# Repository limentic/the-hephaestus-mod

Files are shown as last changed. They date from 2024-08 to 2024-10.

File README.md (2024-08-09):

# The Hephaestus Mod

## ⚠️ DISCLAIMER ⚠️
Magic Keyboard is a trademark of Apple Inc.\
Apple Magic Keyboard is a trademark of Apple Inc.\
Touch ID is a trademark of Apple Inc.\
This project is not affiliated with Apple Inc. in any way.

The Hephaestus Mod is an independent project created by hardware enthusiasts. It is not endorsed, sponsored, ore supported by Apple Inc. Use this project at your own risk. Modifying your Magic Keyboard WILL void any warranty provided by Apple Inc.

## Introduction
The Hephaestus Mod is an open-source hardware modification for the Apple Magic Keyboard. This project aims create a mechanical keyboard using the Apple Magic Keyboard as a base.

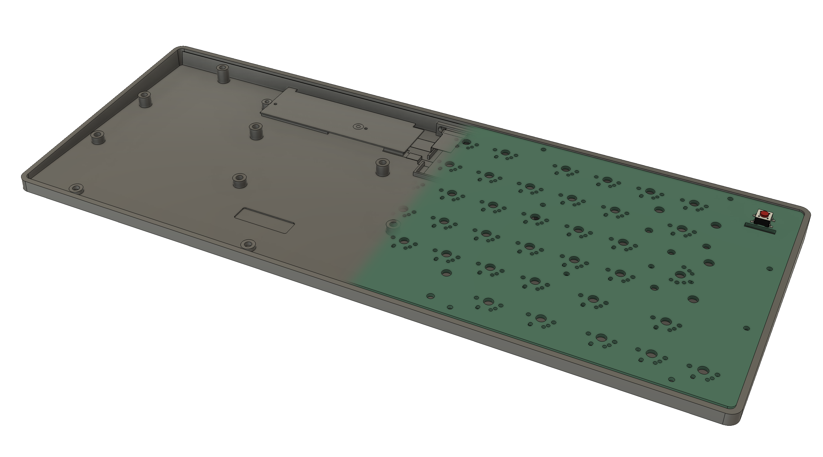
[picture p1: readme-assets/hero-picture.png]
Photomontage of a 3D render of the custom 3D printed case with the half right of the custom PCB on top of it.


## Getting Started
The Hephaestus Mod project is organized into the following directories:
- `ECAD-files/` - Contains the KiCad project files for the Hephaestus Mod.
    In this directory, you will find the following subdirectories:
    - `dev-board/` - Contains the KiCad project files for the development board. This board was used to test out if the reverse engineered keyboard matrix was correct.
    It can also be repurposed as a breakout board for the matrix connector. \
    **Be careful!** The revision 1.0 of the board contains errors for the 9, TAB and Option Right keys. I will make another revision of the dev board when I have time.
    - `prod-board/` - Contains the KiCad project files for the production board. This board is the version of the Hephaestus Mod that is intended to be used. \
    **Be careful!** For the moment this board is still not tested. It is still in manufacturing. I will update this README when I have tested it and confirmed that it works.
    - `touch-id-ribbon` - Contains the KiCad project files for the Touch ID ribbon cable. This cable is used to connect the Touch ID connector on the Apple motherboard to the production board.
- `MCAD-files/` - Contains the .STEP files of the Hephaestus Mod.
    - `hephaestus-case.step` - The case for the Hephaestus Mod.
    - `hephaestus-main-board.step` - The 3D model of the production board.
    - `magic-keyboard-battery.step` - The 3D model of the Magic Keyboard battery.
    - `magic-keyboard-motherboard.step` - The 3D model of the Magic Keyboard motherboard.

## Presumed Keyboard Matrices
You can check the presumed keyboard matrices below :
- [AZERTY Keyboard Matrix](./matrices/AZERTY.md)

## Build Instructions
🚧 **This section will be updated with instructions on how to get started with the Hephaestus Mod when the project is considered done.** 🚧

## License
This project is licensed under the CERN-OHL-S. See the [LICENSE](LICENSE) file for details.

## Contributing
We welcome contributions! Please read our [contributing guidelines](CONTRIBUTING.md) for more information on how to get involved.

## Contact
For questions, issues, or suggestions, please open an issue on our [GitHub repository](https://github.com/limentic/the-hephaestus-mod).

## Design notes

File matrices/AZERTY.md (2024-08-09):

## Key pins :
| Keys | Pin A | Pin B |
|---|---|---|
| ESC | 7 | 27 |
| F1 | 3 | 26 |
| F2 | 7 | 26 |
| F3 | 8 | 26 |
| F4 | 17 | 26 |
| F5 | 21 | 26 |
| F6 | 29 | 26 |
| F7 | 25 | 26 |
| F8 | 28 | 26 |
| F9 | 30 | 26 |
| F10 | 24 | 27 |
| F11 | 3 | 27 |
| F12 | 3 | 19 |
| # | 8 | 19 |
| 1 | 3 | 1 |
| 2 | 7 | 1 |
| 3 | 8 | 1 |
| 4 | 17 | 1 |
| 5 | 21 | 1 |
| 6 | 29 | 1 |
| 7 | 25 | 1 |
| 8 | 28 | 1 |
| 9 | 30 | 1 |
| 0 | 23 | 27 |
| ° | 21 | 27 |
| _ | 29 | 19 |
| BACKSPACE | 3 | 22 |
| TAB | 7 | 22 |
| A | 3 | 15 |
| Z | 7 | 2 |
| E | 8 | 16 |
| R | 17 | 2 |
| T | 21 | 15 |
| Y | 29 | 15 |
| U | 25 | 15 |
| I | 28 | 15 |
| O | 30 | 15 |
| P | 11 | 27 |
| ¨ | 21 | 19 |
| * | 17 | 19 |
| ENTER | 9 | 27 |
| CAPS_LOCK | 11 | 22 |
| Q | 3 | 18 |
| S | 7 | 13 |
| D | 8 | 14 |
| F | 17 | 18 |
| G | 21 | 13 |
| H | 29 | 18 |
| J | 25 | 18 |
| K | 28 | 18 |
| L | 30 | 18 |
| M | 25 | 27 |
| % | 25 | 22 |
| £ | 30 | 27 |
| SHIFT_L | 9 | 15 |
| > | 7 | 19 |
| W | 3 | 20 |
| X | 7 | 20 |
| C | 8 | 20 |
| V | 17 | 14 |
| B | 21 | 14 |
| N | 29 | 20 |
| ? | 25 | 20 |
| . | 28 | 20 |
| / | 30 | 20 |
| + | 29 | 27 |
| SHIFT_R | 9 | 26 |
| FN | 21 | 22 |
| CTRL | 11 | 1 |
| OPTION_L | 24 | 18 |
| COMMAND_L | 23 | 20 |
| SPACE | 24 | 16 |
| COMMAND_R | 23 | 19 |
| OPTION_R | 24 | 22 |
| LEFT_ARROW | 25 | 19 |
| UP_ARROW | 28 | 27 |
| DOWN_ARROW | 28 | 22 |
| RIGHT_ARROW | 30 | 19 |

## Other pins :
| Label | Pins | Notes |
|---|---|---|
| CAPS_LOCK_LED_+ | 5-6 | ~3,23V |
| CAPS_LOCK_LED_- | 10 | Not connected to GND |
| NC (GND) | 4,12,33-40 | |
| PWR | 31-32 | |

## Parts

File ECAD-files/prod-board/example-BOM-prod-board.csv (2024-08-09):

Item | Designator | Qty | Manufacturer | Mfg Part | Description/Value | Package/Footprint | Type | Notes
1 | D1 | 1 | Lite-On | LTST-C170TGKT | LED 3.2V 20mA 525nm 0805 SMD | 0805 | SMD | Accepts alternatives. Any green led with the same characteristics is OK.
2 | J1 | 1 | Hirose | FH12-40S-0.5SH | Connector 1x40 P0.50mm | Non-standard | SMD
3 | J2 | 1 | Hirose | TF22-16S-0.175SHW(800) | Connector 2x8 P0.35mm | Non-standard | SMD
4 | J3 | 1 | Molex | 505066-1222 | Connector 2x6 P0.35mm | Non-standard | SMD
5 | K_SPACE0,K_SPACE1,K_SPACE2,K_SPACE3,K_SPACE4,K_SPACE5,K_SPACE6,K_SPACE7,K_SPACE8,K_SPACE9,K_SPACE10,K_SPACE11,K_SPACE12,K_SPACE14,K_SPACE15,K_SPACE16,K_SPACE17,K_SPACE18,K_SPACE19,K_SPACE20,K_SPACE21,K_SPACE22,K_SPACE23,K_SPACE24,K_SPACE25,K_SPACE26,K_SPACE27,K_SPACE28,K_SPACE29,K_SPACE30,K_SPACE31,K_SPACE32,K_SPACE33,K_SPACE34,K_SPACE35,K_SPACE36,K_SPACE37,K_SPACE38,K_SPACE39,K_SPACE40,K_SPACE41,K_SPACE42,K_SPACE43,K_SPACE44,K_SPACE45,K_SPACE46,K_SPACE47,K_SPACE48,K_SPACE49,K_SPACE50,K_SPACE51,K_SPACE52,K_SPACE53,K_SPACE54,K_SPACE55,K_SPACE56,K_SPACE57,K_SPACE58,K_SPACE59,K_SPACE60,K_SPACE61,K_SPACE62,K_SPACE63,K_SPACE64,K_SPACE65,K_SPACE66,K_SPACE67,K_SPACE68,K_SPACE69,K_SPACE70,K_SPACE71,K_SPACE72,K_SPACE73,K_SPACE74,K_SPACE75,K_SPACE76,K_SPACE77,K_SPACE78 | 78 | Cherry | MX1A-E1NW | Switch SPST Cherry MX Blue (PCB Mount) | Non-standard | thru-hole
6 | SW1 | 1 | Molex | 53261-0271 | Connector 1x2 P1.25mm | Non-standard | SMD
7 | SW2 | 1 | C&K | PTS645-SK-50-SMTR92-LFS | Switch SPST | Non-standard | SMD | Accepts alternatives. The stem should be around 1.5mm.

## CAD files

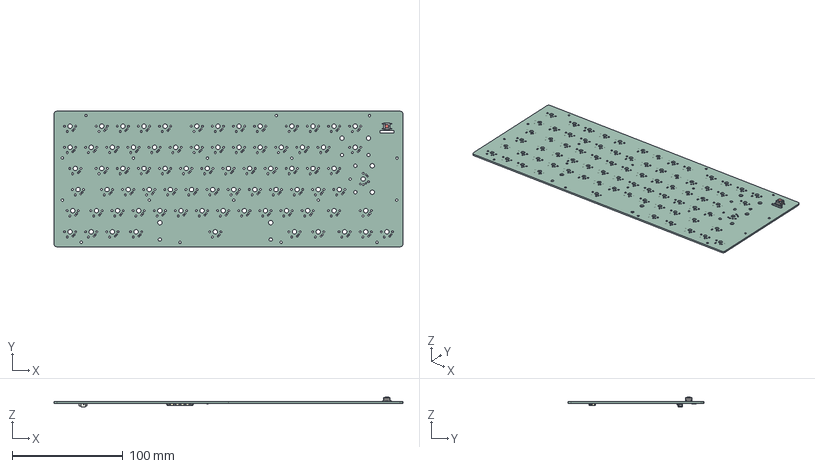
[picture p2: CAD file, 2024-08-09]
MCAD-files/hephaestus-main-board.step
314.8 x 122.3 x 9.40 mm
SW_SPST_PTS645_1
Hirose_FH12_xxS_0_5SH_Parametric_v0_1
Molex_53261_0271
_autosave-keyboard_PCB

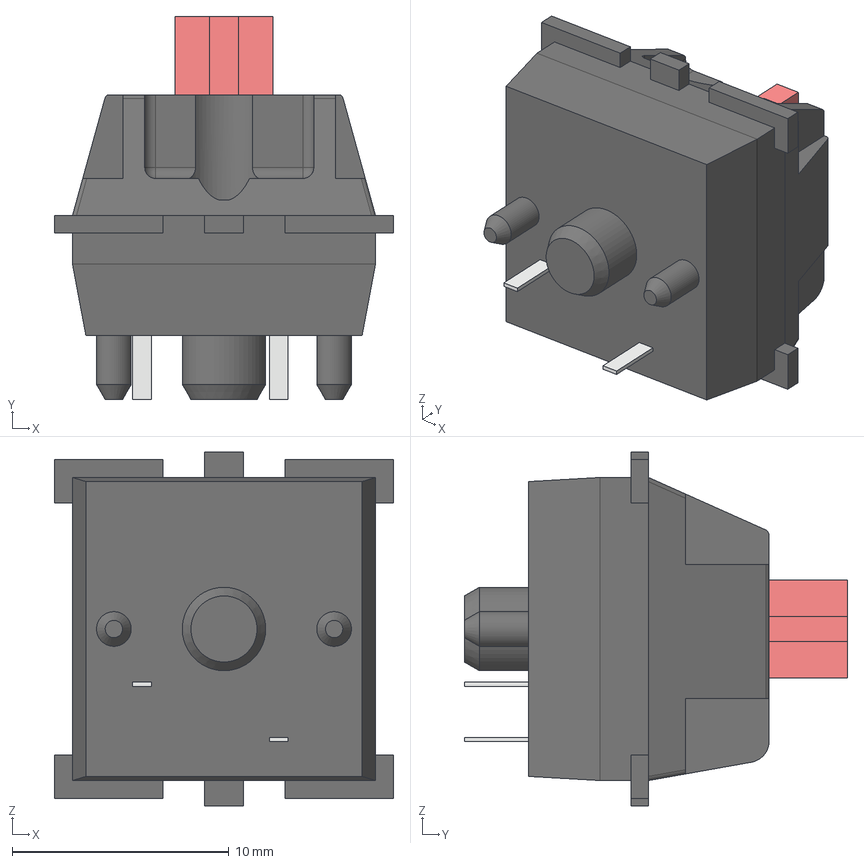
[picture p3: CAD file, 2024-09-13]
ECAD-files/prod-board/cherry-mx-switch/switch.step
15.6 x 17.7 x 16.3 mm

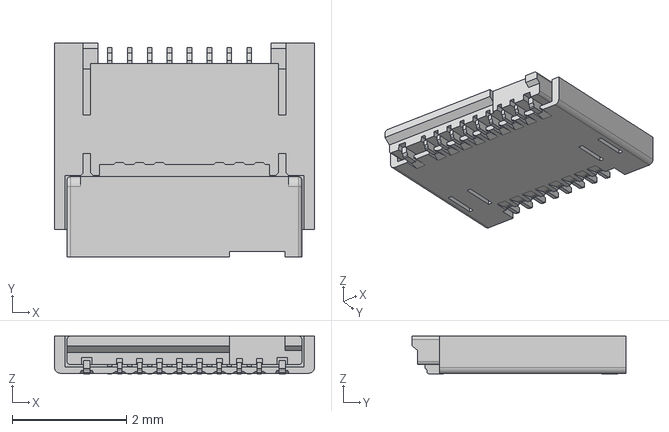
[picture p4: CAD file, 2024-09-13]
ECAD-files/prod-board/TF22-16S/TF22-16S-0.175SHW(800)_4800346000_3D_IGS.igs
4.55 x 3.75 x 0.66 mm

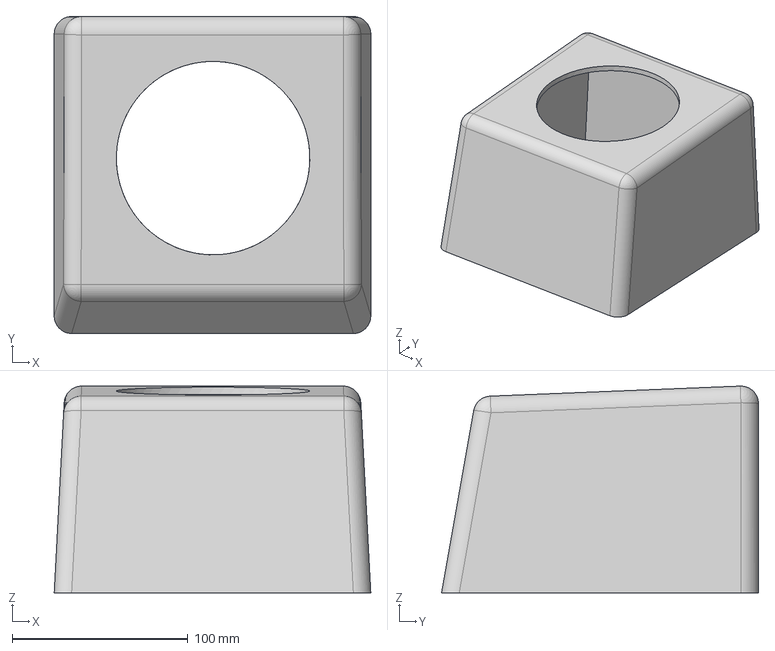
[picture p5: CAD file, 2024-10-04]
MCAD-files/keycap-cover.step
180.0 x 180.2 x 117.6 mm

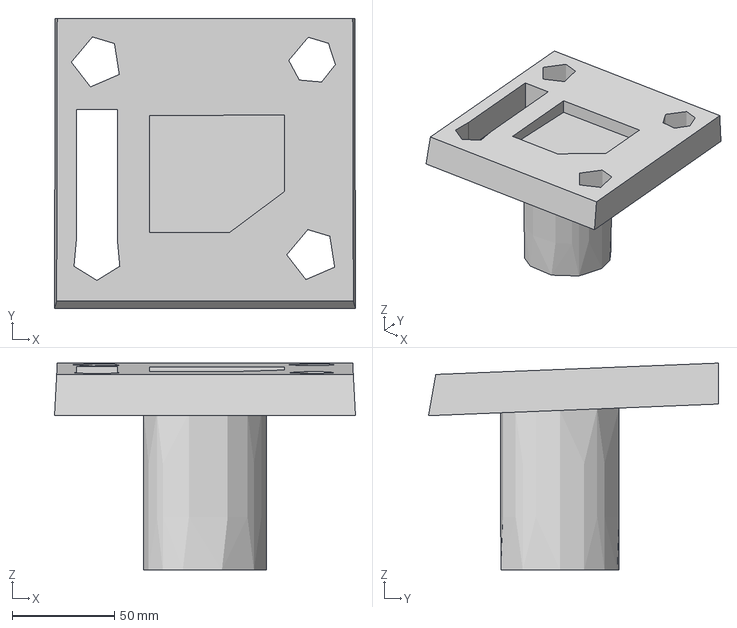
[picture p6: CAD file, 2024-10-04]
MCAD-files/keycap-stem.step
147.1 x 141.7 x 101.1 mm

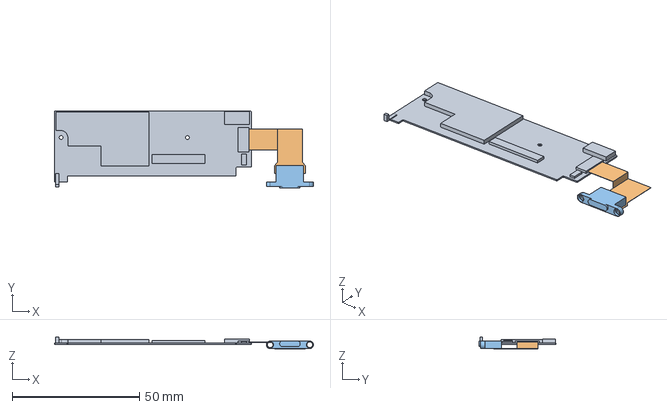
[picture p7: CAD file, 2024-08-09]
MCAD-files/magic-keyboard-motherboard.step
101.6 x 30.3 x 4.63 mm

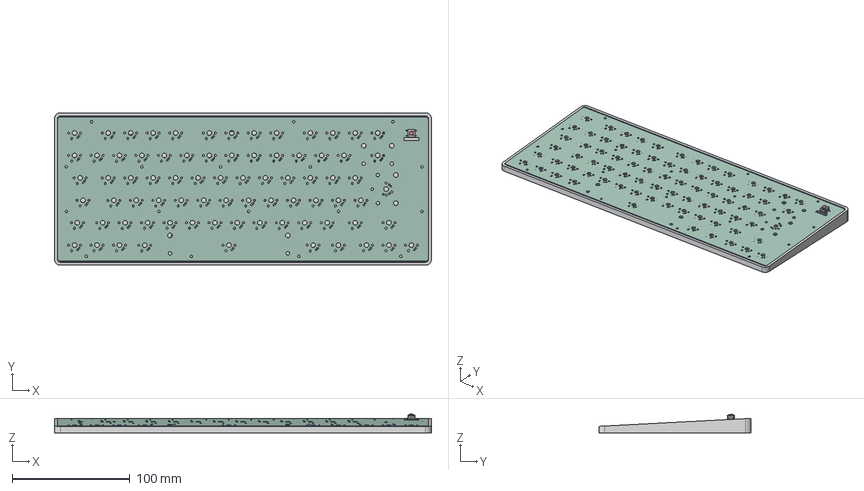
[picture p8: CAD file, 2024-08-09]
MCAD-files/hephaestus-case.step
319.8 x 129.3 x 15.8 mm
SW_SPST_PTS645_1
Hirose_FH12_xxS_0_5SH_Parametric_v0_1
Molex_53261_0271
_autosave-keyboard_PCB
magic-keyboard-motherboard
magic-keyboard-battery

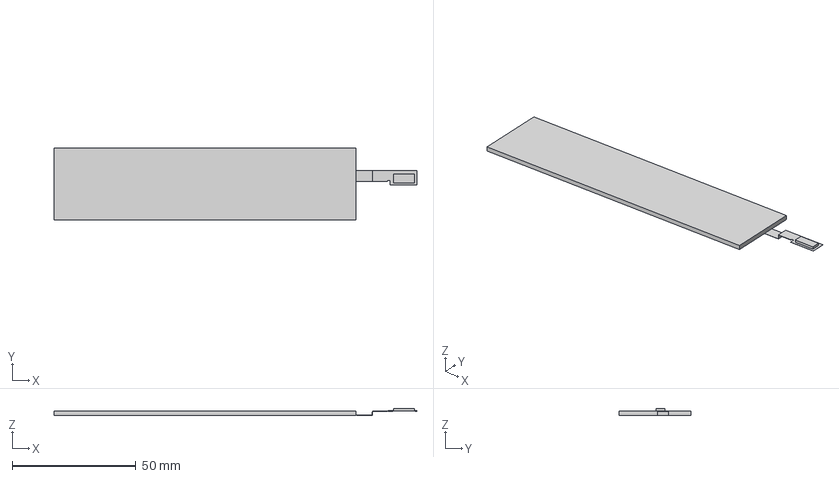
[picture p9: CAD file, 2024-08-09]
MCAD-files/magic-keyboard-battery.step
146.7 x 29.0 x 2.81 mm

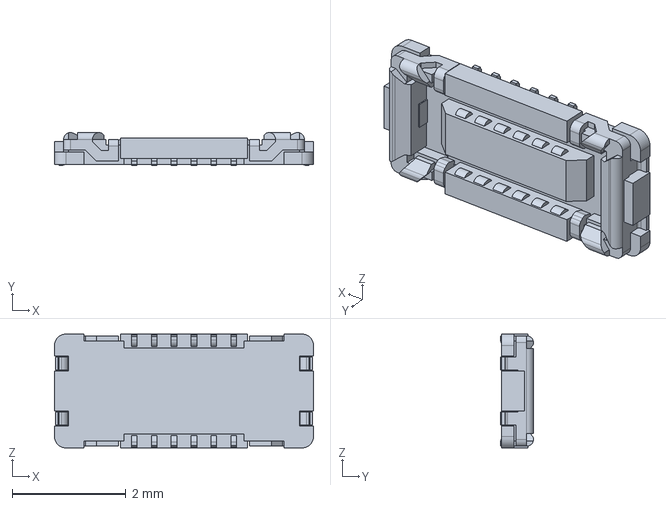
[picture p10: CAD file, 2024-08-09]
ECAD-files/prod-board/505066-1222/505066-1222.stp
4.55 x 0.58 x 2.00 mm

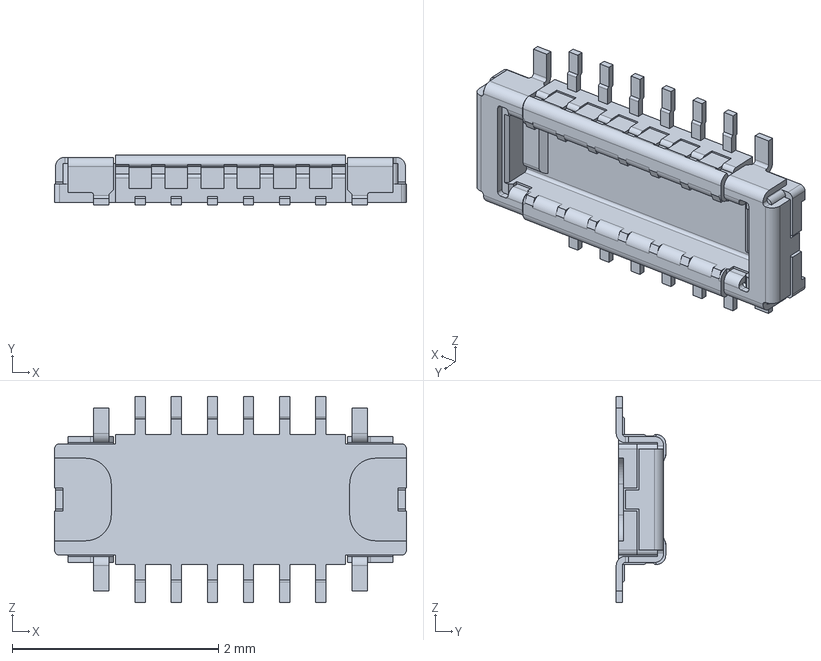
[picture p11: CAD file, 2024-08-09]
ECAD-files/touch-id-ribbon/505070-1222/505070-1222.step
3.41 x 0.48 x 2.00 mm

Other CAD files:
ECAD-files/touch-id-ribbon/505070-1222/505070-1222.stp

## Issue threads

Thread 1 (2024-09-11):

is the touchid housing keycap part of this project?

aescolastico, 2024-09-11:
hello,
first off, cool project. this is amazing work.

second, i saw your post on GH where you prototyped a keycap for the touch id sensor.
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

would you be willing to add that to the repo? or if it is already, can you please direct me to that file?

im planning on doing a much less integrated and involved mod, where i simply store the control board in an existing mech keeb's housing and replace my escape key cap with a touch id one, feeding the ribbon behind the mechs pcb.

limentic, 2024-09-13:
Hello, sorry for the delay.
I lost the original file and had to remake it for someone who emailed me a few weeks ago.
I can create a new branch with the keycap so you can test it and let me know if it's okay.

aescolastico, 2024-09-13:
> Hello, sorry for the delay. I lost the original file and had to remake it for someone who emailed me a few weeks ago. I can create a new branch with the keycap so you can test it and let me know if it's okay.

one question, what unit are the keycap and stem stl files in?

limentic, 2024-09-13:
milimeters :)

aescolastico, 2024-10-04:
> Hello, sorry for the delay. I lost the original file and had to remake it for someone who emailed me a few weeks ago. I can create a new branch with the keycap so you can test it and let me know if it's okay.

so i got a few pieces printed in different resin materials. it seems that the stem has too much play on the "female" side to stay on the switch. it wobbles when you try to press it. it guess its also possible the print was just off?

would you happen to still have the source files? i may try to take a stab at modifying them to closer match the profile of my LP key caps. the stem is shorter and so is the key cap face.

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

limentic, 2024-10-04:
I'm so sorry for the bad files I've provided to you . As I've said before, I don't have the original files, thoses were re-creations, I've made new files in .step from the previous version of the keycap.
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

Let me know if you tweak it and make it work !
Good luck!

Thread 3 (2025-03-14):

Swapping the lightning connector for USB-C

ataulm, 2025-03-14:
Great write up of the project on GH! 👏

I disassembled my Magic KB this week with the intention of baking just the touch ID into my desk.

I noticed on the first post of the thread that you mentioned that you want to swap the lightning port for a usb c port: did you have a plan for this yet?

I'd like to do the same but no idea if I can buy a port that has the same connection.

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

Also unclear to me whether I can shorten this PCB if I'm only interested in the touch ID - presumably that metal cover is housing the controller 🥲

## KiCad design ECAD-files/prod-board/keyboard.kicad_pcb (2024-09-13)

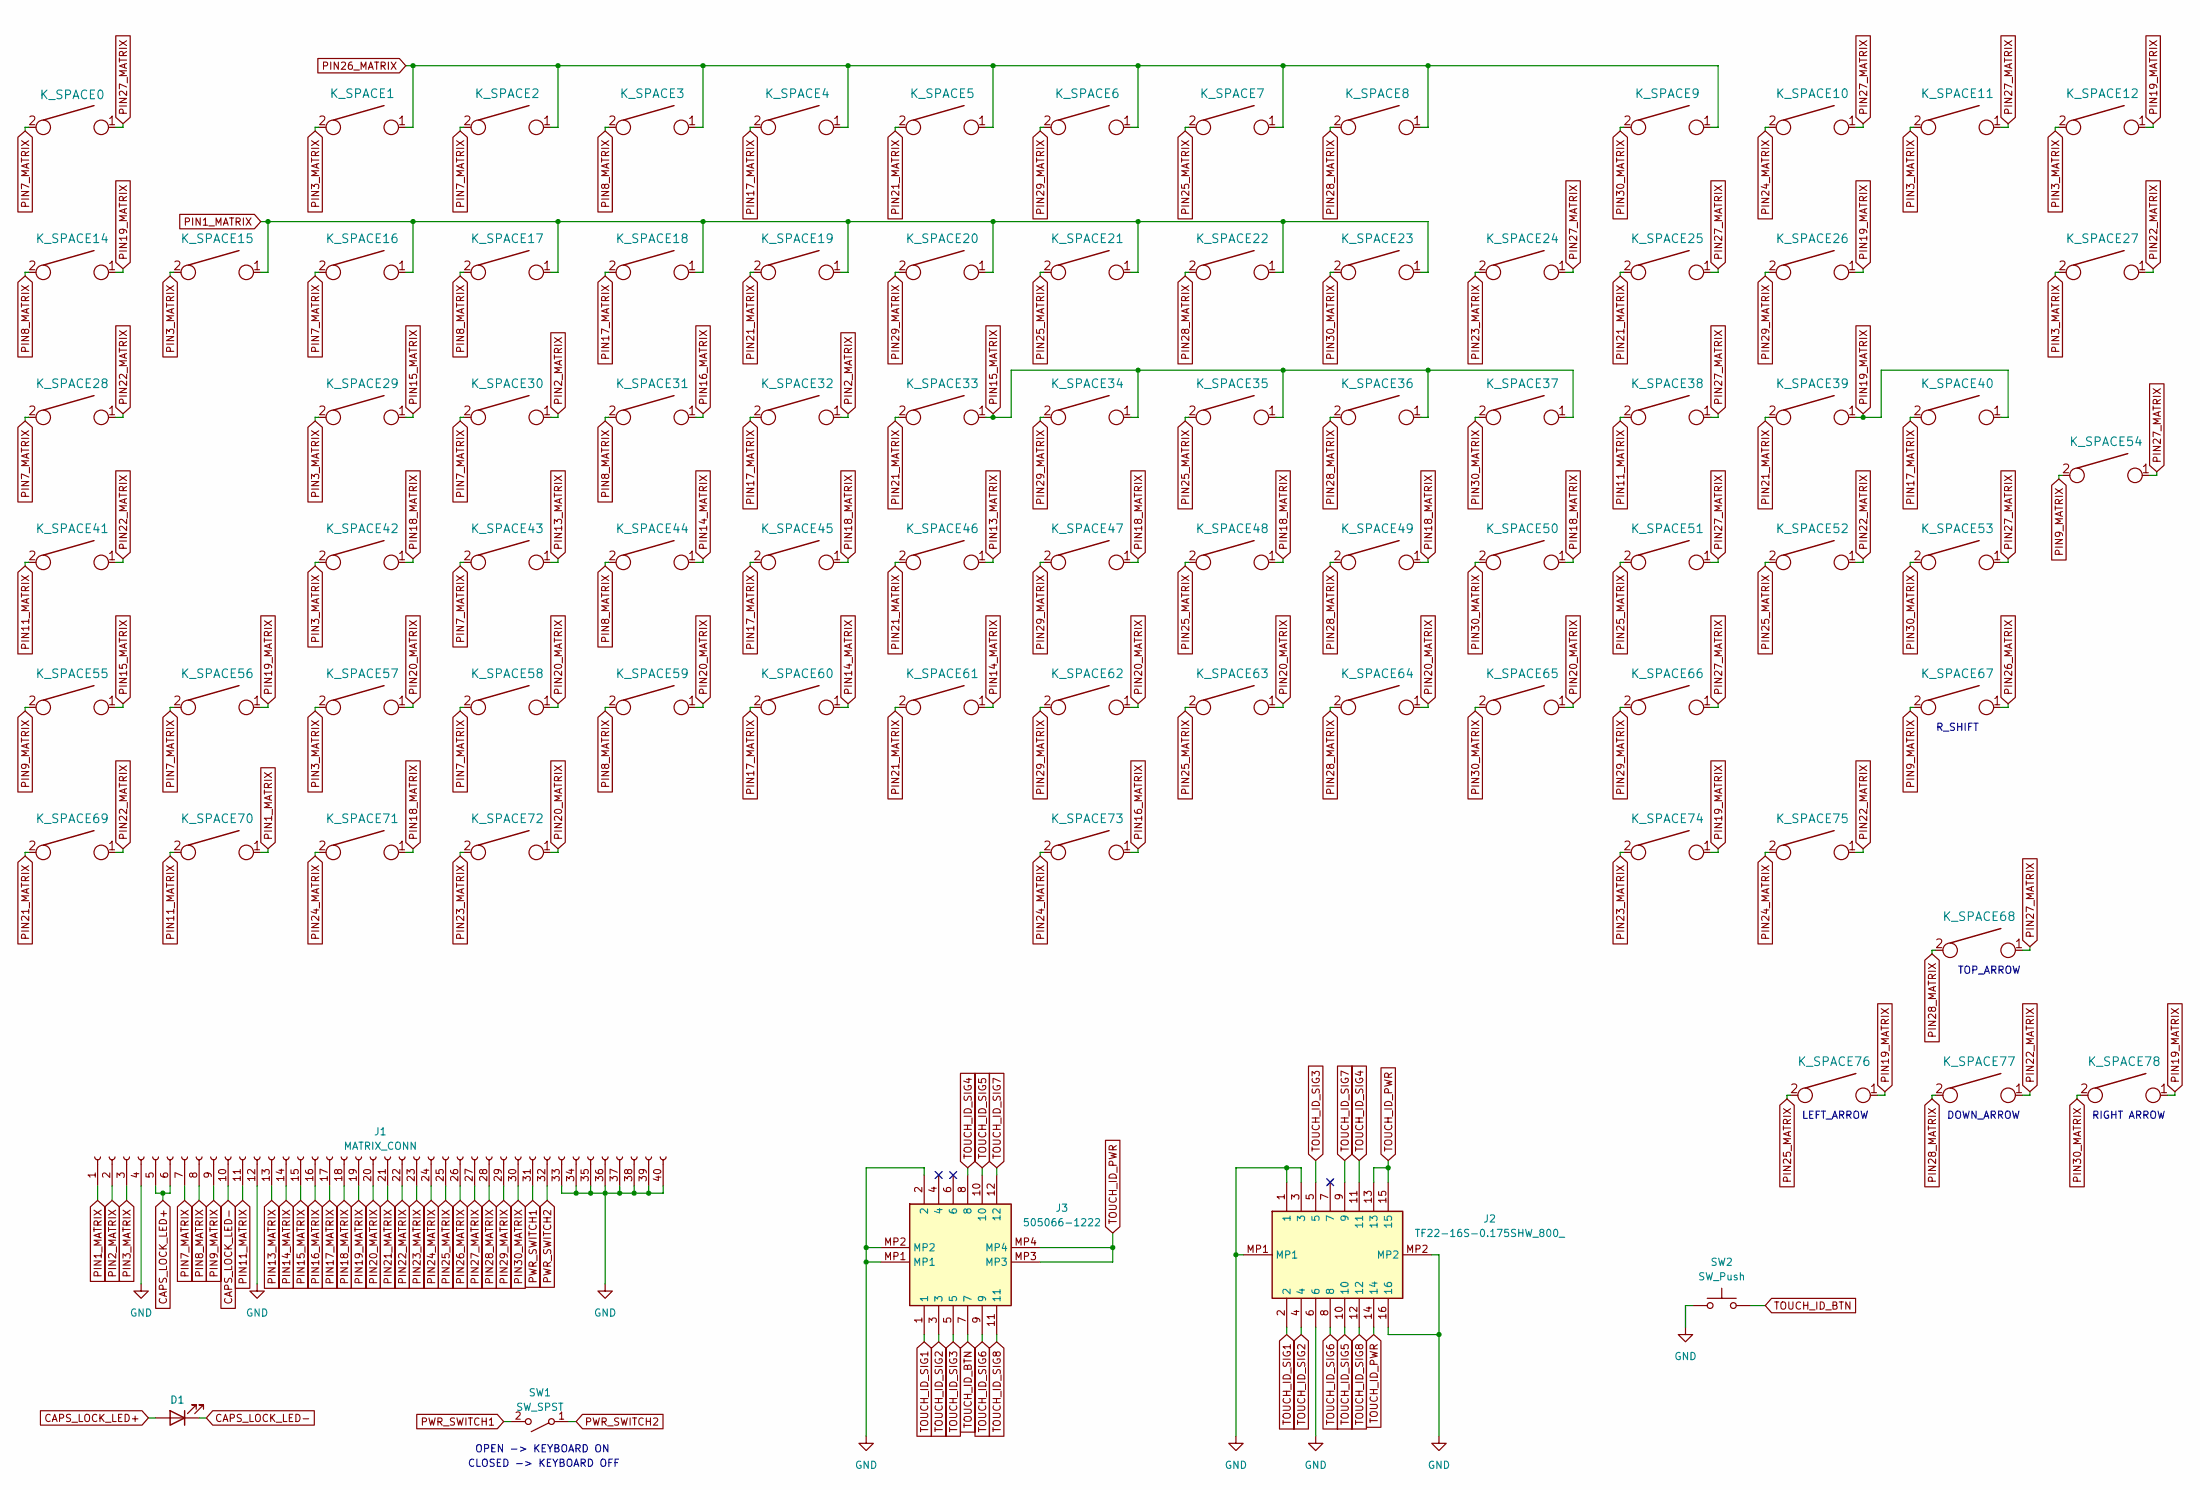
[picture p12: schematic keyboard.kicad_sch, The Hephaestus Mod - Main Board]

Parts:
D1: LED; LED_0805_2012Metric
J1: MATRIX_CONN; Hirose_FH12-40S-0.5SH_1x40-1MP_P0.50mm_Horizontal
J2: TF22-16S-0.175SHW_800_; TF2216S0175SHW800; Manufacturer_Part_Number TF22-16S-0.175SHW(800)
J3: 505066-1222; 5050661222; Mouser Part Number 538-505066-1222
K_SPACE0, K_SPACE1, K_SPACE2, K_SPACE3, K_SPACE4, K_SPACE5, K_SPACE6, K_SPACE7, K_SPACE8, K_SPACE9, K_SPACE10, K_SPACE11, K_SPACE12, K_SPACE14, K_SPACE15, K_SPACE16, K_SPACE17, K_SPACE18, K_SPACE19, K_SPACE20, K_SPACE21, K_SPACE22, K_SPACE23, K_SPACE24, K_SPACE25, K_SPACE26, K_SPACE29, K_SPACE30, K_SPACE31, K_SPACE32, K_SPACE33, K_SPACE34, K_SPACE35, K_SPACE36, K_SPACE37, K_SPACE38, K_SPACE39, K_SPACE40, K_SPACE42, K_SPACE43, K_SPACE44, K_SPACE45, K_SPACE46, K_SPACE47, K_SPACE48, K_SPACE49, K_SPACE50, K_SPACE51, K_SPACE52, K_SPACE53, K_SPACE56, K_SPACE57, K_SPACE58, K_SPACE59, K_SPACE60, K_SPACE61, K_SPACE62, K_SPACE63, K_SPACE64, K_SPACE65, K_SPACE66, K_SPACE68, K_SPACE69, K_SPACE70, K_SPACE71, K_SPACE75, K_SPACE76, K_SPACE77, K_SPACE78: KEYSW; MX-1U-NoLED
K_SPACE27: KEYSW; MX-2U-NoLED
K_SPACE28, K_SPACE67: KEYSW; MX-1.5U-NoLED
K_SPACE41: KEYSW; MX-1.75U-NoLED
K_SPACE54: KEYSW; MX-ISO-NoLED
K_SPACE55, K_SPACE72, K_SPACE74: KEYSW; MX-1.25U-NoLED
K_SPACE73: KEYSW; MX-6.25U-NoLED
SW1: SW_SPST; Molex_PicoBlade_53261-0271_1x02-1MP_P1.25mm_Horizontal
SW2: SW_Push; SW_SPST_PTS645

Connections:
CAPS_LOCK_LED+: D1.2 (A), J1.5, J1.6
CAPS_LOCK_LED-: D1.1 (K), J1.10
GND: J1.4, J1.12, J1.33, J1.34, J1.35, J1.36, J1.37, J1.38, J1.39, J1.40, J2.1, J2.3, J2.6, J2.16, J2.MP1, J2.MP2, J3.2, J3.MP1, J3.MP2, SW2.1
PIN1_MATRIX: J1.1, K_SPACE15.1, K_SPACE16.1, K_SPACE17.1, K_SPACE18.1, K_SPACE19.1, K_SPACE20.1, K_SPACE21.1, K_SPACE22.1, K_SPACE23.1, K_SPACE70.1
PIN2_MATRIX: J1.2, K_SPACE30.1, K_SPACE32.1
PIN3_MATRIX: J1.3, K_SPACE1.2, K_SPACE11.2, K_SPACE12.2, K_SPACE15.2, K_SPACE27.2, K_SPACE29.2, K_SPACE42.2, K_SPACE57.2
PIN7_MATRIX: J1.7, K_SPACE0.2, K_SPACE2.2, K_SPACE16.2, K_SPACE28.2, K_SPACE30.2, K_SPACE43.2, K_SPACE56.2, K_SPACE58.2
PIN8_MATRIX: J1.8, K_SPACE3.2, K_SPACE14.2, K_SPACE17.2, K_SPACE31.2, K_SPACE44.2, K_SPACE59.2
PIN9_MATRIX: J1.9, K_SPACE54.2, K_SPACE55.2, K_SPACE67.2
PIN11_MATRIX: J1.11, K_SPACE38.2, K_SPACE41.2, K_SPACE70.2
PIN13_MATRIX: J1.13, K_SPACE43.1, K_SPACE46.1
PIN14_MATRIX: J1.14, K_SPACE44.1, K_SPACE60.1, K_SPACE61.1
PIN15_MATRIX: J1.15, K_SPACE29.1, K_SPACE33.1, K_SPACE34.1, K_SPACE35.1, K_SPACE36.1, K_SPACE37.1, K_SPACE55.1
PIN16_MATRIX: J1.16, K_SPACE31.1, K_SPACE73.1
PIN17_MATRIX: J1.17, K_SPACE4.2, K_SPACE18.2, K_SPACE32.2, K_SPACE40.2, K_SPACE45.2, K_SPACE60.2
PIN18_MATRIX: J1.18, K_SPACE42.1, K_SPACE45.1, K_SPACE47.1, K_SPACE48.1, K_SPACE49.1, K_SPACE50.1, K_SPACE71.1
PIN19_MATRIX: J1.19, K_SPACE12.1, K_SPACE14.1, K_SPACE26.1, K_SPACE39.1, K_SPACE40.1, K_SPACE56.1, K_SPACE74.1, K_SPACE76.1, K_SPACE78.1
PIN20_MATRIX: J1.20, K_SPACE57.1, K_SPACE58.1, K_SPACE59.1, K_SPACE62.1, K_SPACE63.1, K_SPACE64.1, K_SPACE65.1, K_SPACE72.1
PIN21_MATRIX: J1.21, K_SPACE5.2, K_SPACE19.2, K_SPACE25.2, K_SPACE33.2, K_SPACE39.2, K_SPACE46.2, K_SPACE61.2, K_SPACE69.2
PIN22_MATRIX: J1.22, K_SPACE27.1, K_SPACE28.1, K_SPACE41.1, K_SPACE52.1, K_SPACE69.1, K_SPACE75.1, K_SPACE77.1
PIN23_MATRIX: J1.23, K_SPACE24.2, K_SPACE72.2, K_SPACE74.2
PIN24_MATRIX: J1.24, K_SPACE10.2, K_SPACE71.2, K_SPACE73.2, K_SPACE75.2
PIN25_MATRIX: J1.25, K_SPACE7.2, K_SPACE21.2, K_SPACE35.2, K_SPACE48.2, K_SPACE51.2, K_SPACE52.2, K_SPACE63.2, K_SPACE76.2
PIN26_MATRIX: J1.26, K_SPACE1.1, K_SPACE2.1, K_SPACE3.1, K_SPACE4.1, K_SPACE5.1, K_SPACE6.1, K_SPACE7.1, K_SPACE8.1, K_SPACE9.1, K_SPACE67.1
PIN27_MATRIX: J1.27, K_SPACE0.1, K_SPACE10.1, K_SPACE11.1, K_SPACE24.1, K_SPACE25.1, K_SPACE38.1, K_SPACE51.1, K_SPACE53.1, K_SPACE54.1, K_SPACE66.1, K_SPACE68.1
PIN28_MATRIX: J1.28, K_SPACE8.2, K_SPACE22.2, K_SPACE36.2, K_SPACE49.2, K_SPACE64.2, K_SPACE68.2, K_SPACE77.2
PIN29_MATRIX: J1.29, K_SPACE6.2, K_SPACE20.2, K_SPACE26.2, K_SPACE34.2, K_SPACE47.2, K_SPACE62.2, K_SPACE66.2
PIN30_MATRIX: J1.30, K_SPACE9.2, K_SPACE23.2, K_SPACE37.2, K_SPACE50.2, K_SPACE53.2, K_SPACE65.2, K_SPACE78.2
PWR_SWITCH1: J1.31, SW1.2 (B)
PWR_SWITCH2: J1.32, SW1.1 (A)
TOUCH_ID_BTN: J3.7, SW2.2
TOUCH_ID_PWR: J2.13, J2.14, J2.15, J3.MP3, J3.MP4
TOUCH_ID_SIG1: J2.2, J3.1
TOUCH_ID_SIG2: J2.4, J3.3
TOUCH_ID_SIG3: J2.5, J3.5
TOUCH_ID_SIG4: J2.11, J3.8
TOUCH_ID_SIG5: J2.10, J3.10
TOUCH_ID_SIG6: J2.8, J3.9
TOUCH_ID_SIG7: J2.9, J3.12
TOUCH_ID_SIG8: J2.12, J3.11

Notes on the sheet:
R_SHIFT
DOWN_ARROW
TOP_ARROW
RIGHT ARROW
OPEN -> KEYBOARD ON
CLOSED -> KEYBOARD OFF
LEFT_ARROW

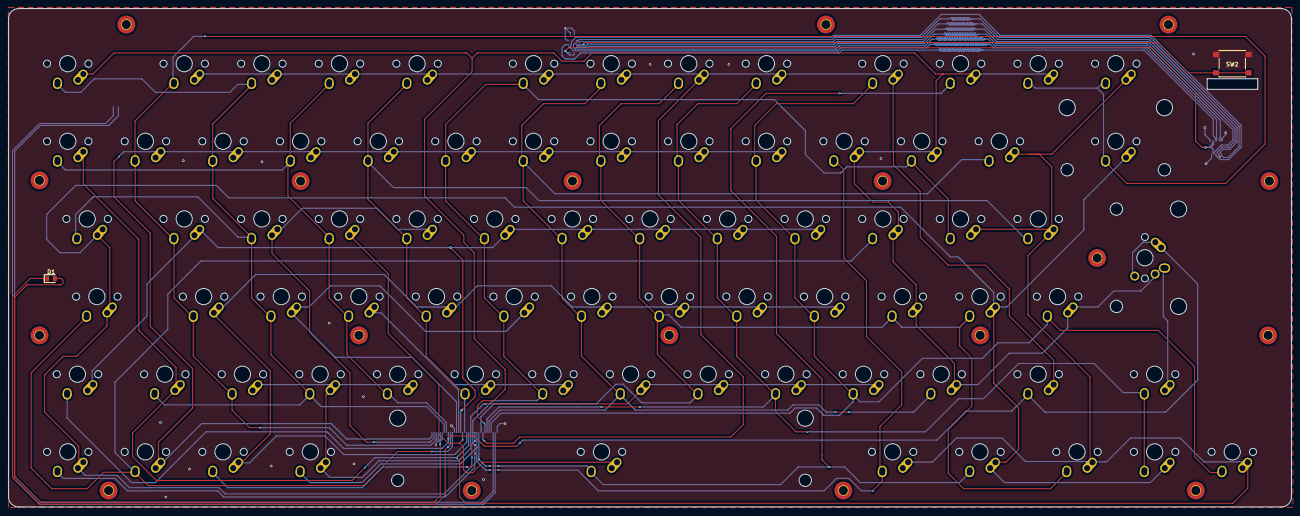
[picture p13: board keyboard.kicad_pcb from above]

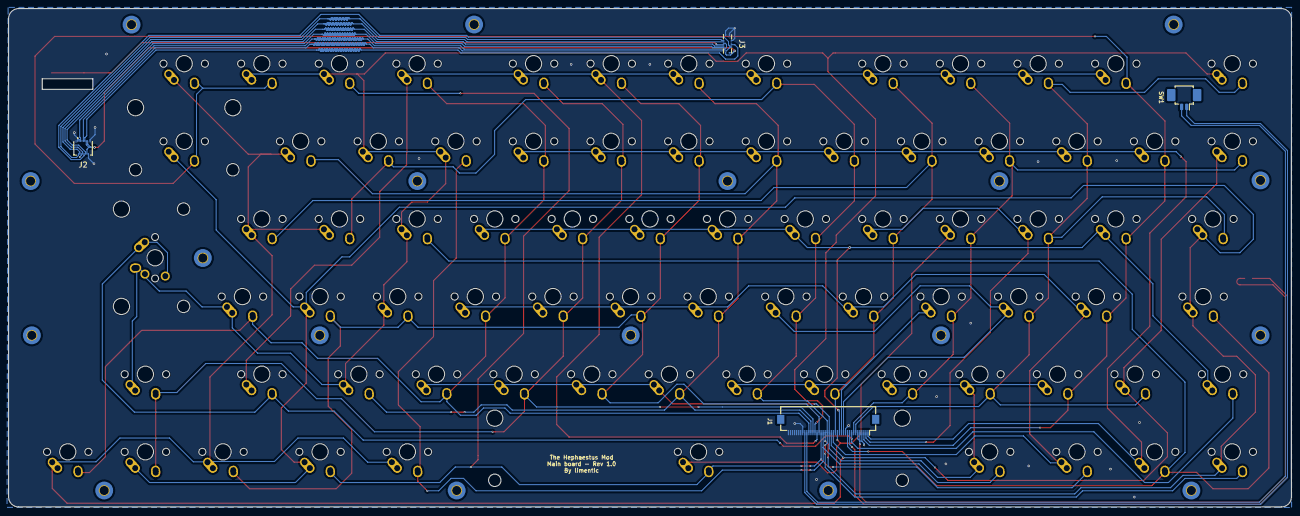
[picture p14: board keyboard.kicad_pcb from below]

Board: 2 copper layers, 314.8 x 122.3 mm, 84 parts (4 on the bottom side), 40 nets.

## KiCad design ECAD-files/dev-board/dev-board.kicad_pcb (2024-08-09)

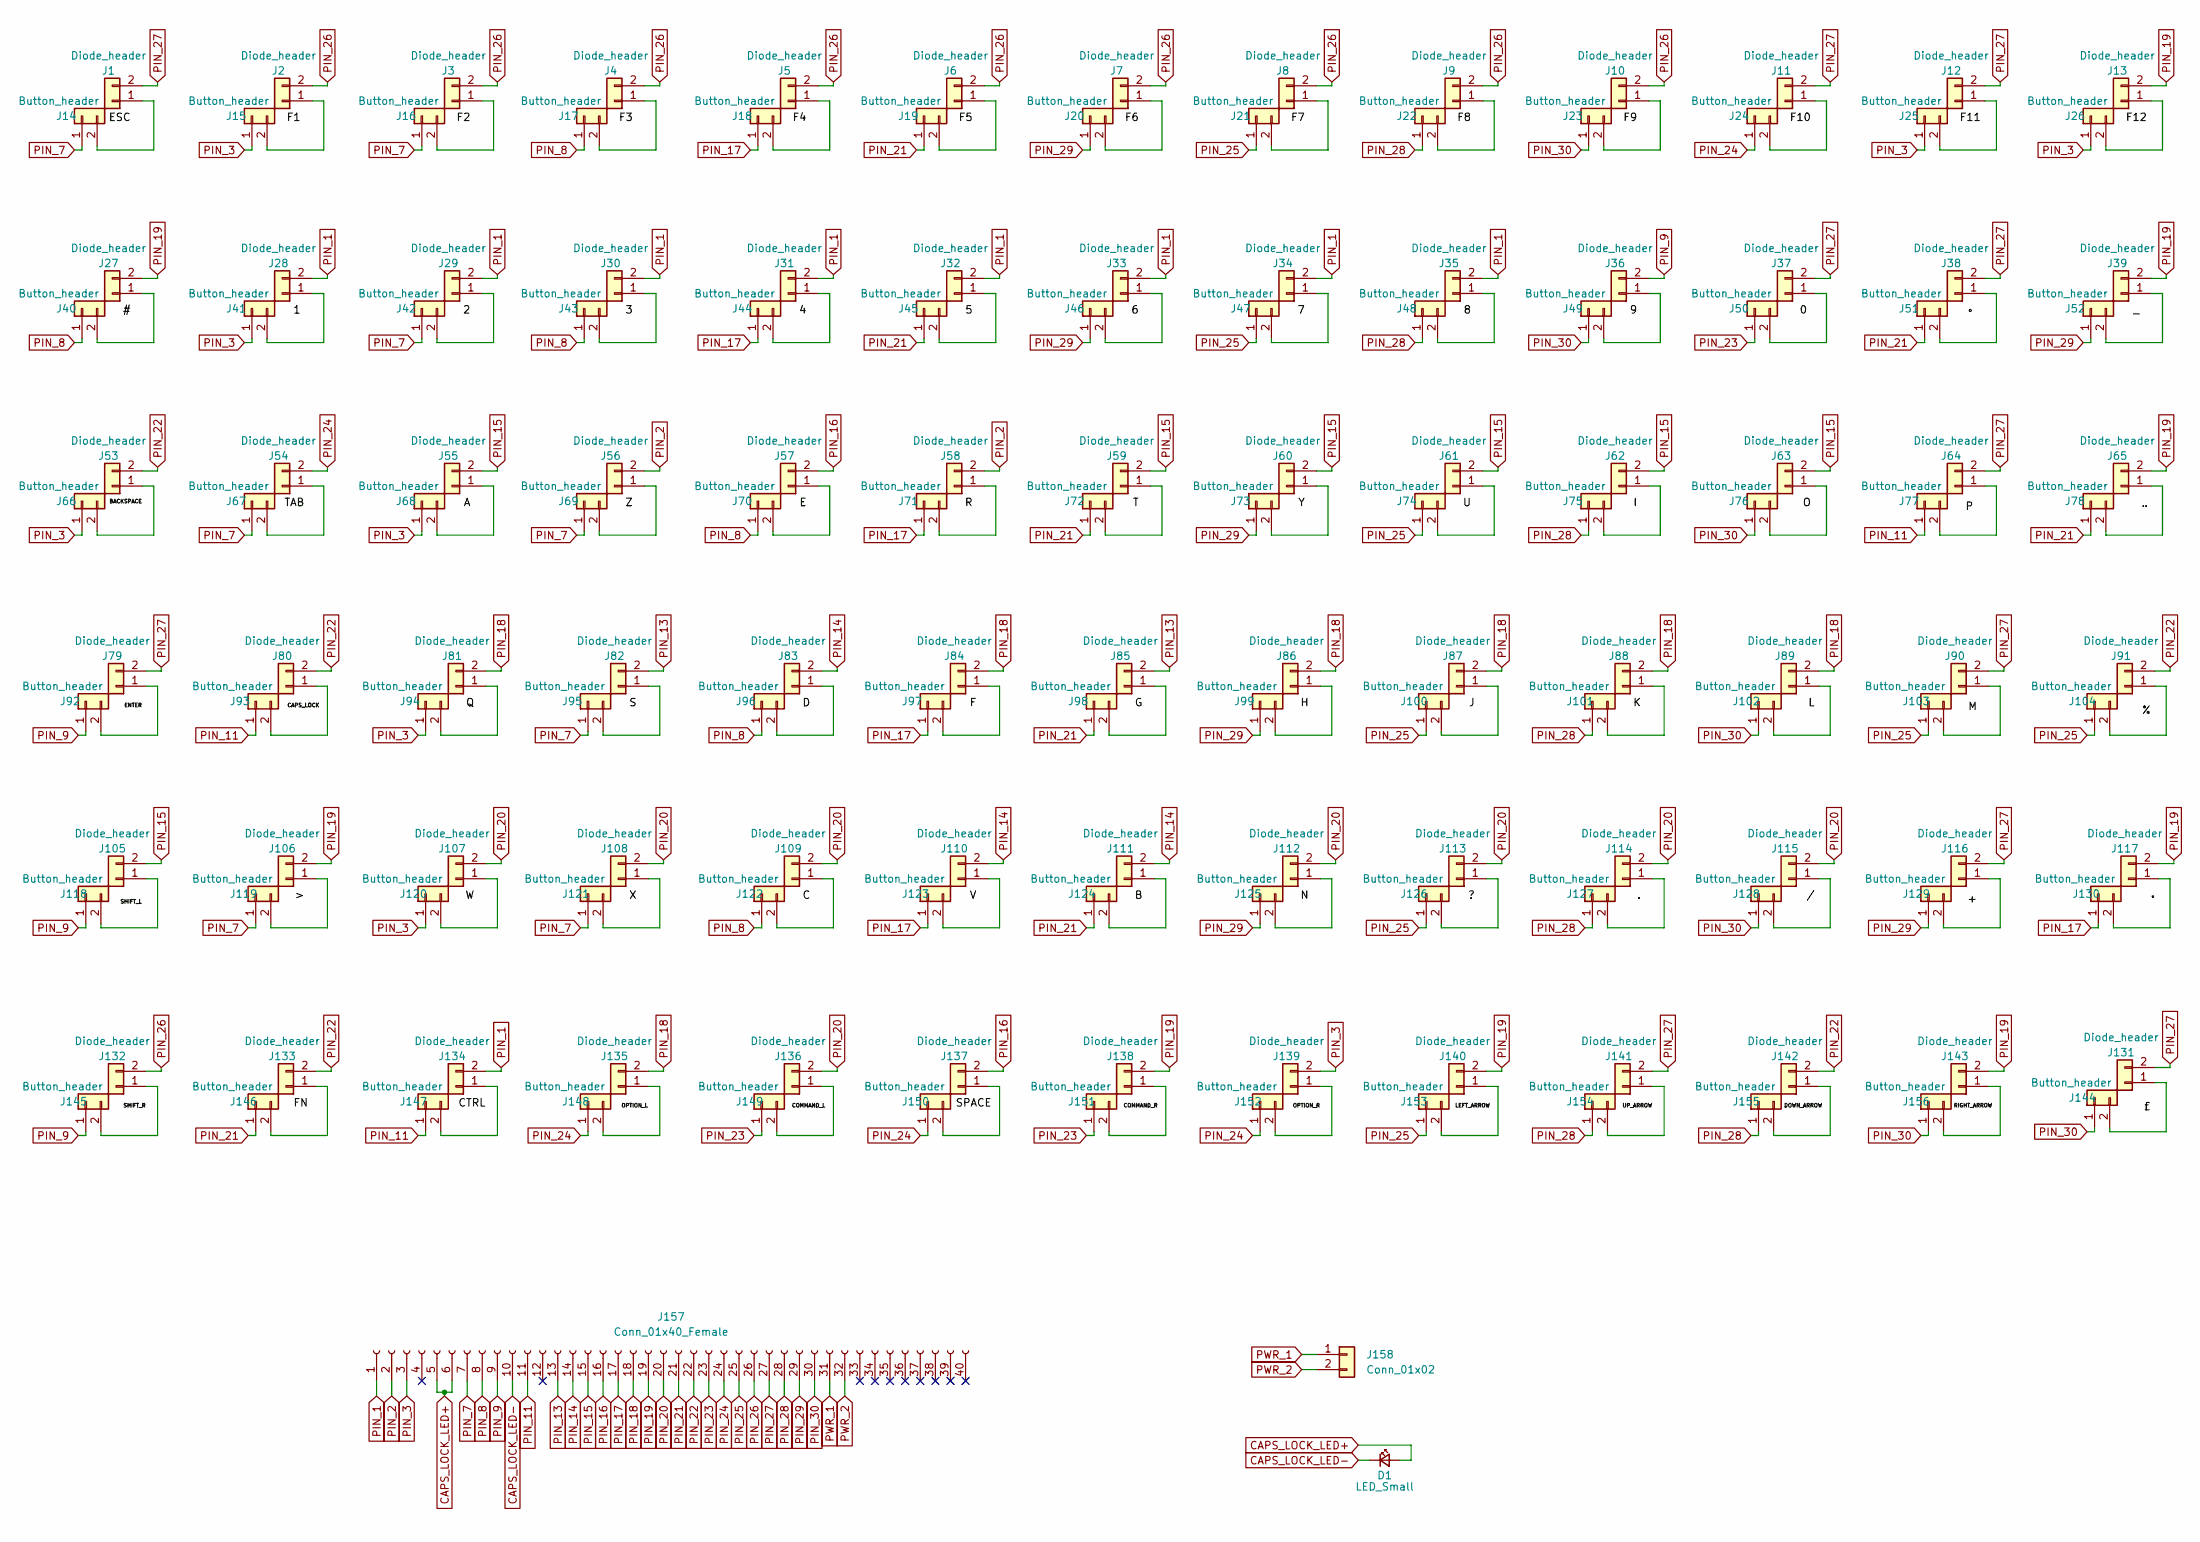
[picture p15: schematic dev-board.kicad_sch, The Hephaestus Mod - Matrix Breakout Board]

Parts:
D1: LED_Small; LED_0805_2012Metric
J1, J2, J3, J4, J5, J6, J7, J8, J9, J10, J11, J12, J13, J27, J28, J29, J30, J31, J32, J33, J34, J35, J36, J37, J38, J39, J53, J54, J55, J56, J57, J58, J59, J60, J61, J62, J63, J64, J65, J79, J80, J81, J82, J83, J84, J85, J86, J87, J88, J89, J90, J91, J105, J106, J107, J108, J109, J110, J111, J112, J113, J114, J115, J116, J117, J131, J132, J133, J134, J135, J136, J137, J138, J139, J140, J141, J142, J143: Diode_header; PinHeader_1x02_P2.54mm_Vertical
J14, J15, J16, J17, J18, J19, J20, J21, J22, J23, J24, J25, J26, J40, J41, J42, J43, J44, J45, J46, J47, J48, J49, J50, J51, J52, J66, J67, J68, J69, J70, J71, J72, J73, J74, J75, J76, J77, J78, J92, J93, J94, J95, J96, J97, J98, J99, J100, J101, J102, J103, J104, J118, J119, J120, J121, J122, J123, J124, J125, J126, J127, J128, J129, J130, J144, J145, J146, J147, J148, J149, J150, J151, J152, J153, J154, J155, J156: Button_header; PinHeader_1x02_P2.54mm_Vertical
J157: Conn_01x40_Female; Hirose_FH12-40S-0.5SH_1x40-1MP_P0.50mm_Horizontal
J158: Conn_01x02; PinHeader_1x02_P2.54mm_Vertical

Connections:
CAPS_LOCK_LED+: D1.2 (A), J157.5, J157.6
CAPS_LOCK_LED-: D1.1 (K), J157.10
unnamed: J1.1, J14.2
unnamed: J10.1, J23.2
unnamed: J11.1, J24.2
unnamed: J12.1, J25.2
unnamed: J13.1, J26.2
unnamed: J2.1, J15.2
unnamed: J3.1, J16.2
unnamed: J4.1, J17.2
unnamed: J5.1, J18.2
unnamed: J6.1, J19.2
unnamed: J7.1, J20.2
unnamed: J8.1, J21.2
unnamed: J9.1, J22.2
unnamed: J27.1, J40.2
unnamed: J28.1, J41.2
unnamed: J29.1, J42.2
unnamed: J30.1, J43.2
unnamed: J31.1, J44.2
unnamed: J32.1, J45.2
unnamed: J33.1, J46.2
unnamed: J34.1, J47.2
unnamed: J35.1, J48.2
unnamed: J36.1, J49.2
unnamed: J37.1, J50.2
unnamed: J38.1, J51.2
unnamed: J39.1, J52.2
unnamed: J53.1, J66.2
unnamed: J54.1, J67.2
unnamed: J55.1, J68.2
unnamed: J56.1, J69.2
unnamed: J57.1, J70.2
unnamed: J58.1, J71.2
unnamed: J59.1, J72.2
unnamed: J60.1, J73.2
unnamed: J61.1, J74.2
unnamed: J62.1, J75.2
unnamed: J63.1, J76.2
unnamed: J64.1, J77.2
unnamed: J65.1, J78.2
unnamed: J79.1, J92.2
unnamed: J80.1, J93.2
unnamed: J81.1, J94.2
unnamed: J82.1, J95.2
unnamed: J83.1, J96.2
unnamed: J84.1, J97.2
unnamed: J85.1, J98.2
unnamed: J86.1, J99.2
unnamed: J87.1, J100.2
unnamed: J88.1, J101.2
unnamed: J89.1, J102.2
unnamed: J90.1, J103.2
unnamed: J91.1, J104.2
unnamed: J105.1, J118.2
unnamed: J106.1, J119.2
unnamed: J107.1, J120.2
unnamed: J108.1, J121.2
unnamed: J109.1, J122.2
unnamed: J110.1, J123.2
unnamed: J111.1, J124.2
unnamed: J112.1, J125.2
unnamed: J113.1, J126.2
unnamed: J114.1, J127.2
unnamed: J115.1, J128.2
unnamed: J116.1, J129.2
unnamed: J117.1, J130.2
unnamed: J131.1, J144.2
unnamed: J132.1, J145.2
unnamed: J133.1, J146.2
unnamed: J134.1, J147.2
unnamed: J135.1, J148.2
unnamed: J136.1, J149.2
unnamed: J137.1, J150.2
unnamed: J138.1, J151.2
unnamed: J139.1, J152.2
unnamed: J140.1, J153.2
unnamed: J141.1, J154.2
unnamed: J142.1, J155.2
unnamed: J143.1, J156.2
PIN_1: J28.2, J29.2, J30.2, J31.2, J32.2, J33.2, J34.2, J35.2, J134.2, J157.1
PIN_2: J56.2, J58.2, J157.2
PIN_3: J15.1, J25.1, J26.1, J41.1, J66.1, J68.1, J94.1, J120.1, J139.2, J157.3
PIN_7: J14.1, J16.1, J42.1, J67.1, J69.1, J95.1, J119.1, J121.1, J157.7
PIN_8: J17.1, J40.1, J43.1, J70.1, J96.1, J122.1, J157.8
PIN_9: J36.2, J92.1, J118.1, J145.1, J157.9
PIN_11: J77.1, J93.1, J147.1, J157.11
PIN_13: J82.2, J85.2, J157.13
PIN_14: J83.2, J110.2, J111.2, J157.14
PIN_15: J55.2, J59.2, J60.2, J61.2, J62.2, J63.2, J105.2, J157.15
PIN_16: J57.2, J137.2, J157.16
PIN_17: J18.1, J44.1, J71.1, J97.1, J123.1, J130.1, J157.17
PIN_18: J81.2, J84.2, J86.2, J87.2, J88.2, J89.2, J135.2, J157.18
PIN_19: J13.2, J27.2, J39.2, J65.2, J106.2, J117.2, J138.2, J140.2, J143.2, J157.19
PIN_20: J107.2, J108.2, J109.2, J112.2, J113.2, J114.2, J115.2, J136.2, J157.20
PIN_21: J19.1, J45.1, J51.1, J72.1, J78.1, J98.1, J124.1, J146.1, J157.21
PIN_22: J53.2, J80.2, J91.2, J133.2, J142.2, J157.22
PIN_23: J50.1, J149.1, J151.1, J157.23
PIN_24: J24.1, J54.2, J148.1, J150.1, J152.1, J157.24
PIN_25: J21.1, J47.1, J74.1, J100.1, J103.1, J104.1, J126.1, J153.1, J157.25
PIN_26: J2.2, J3.2, J4.2, J5.2, J6.2, J7.2, J8.2, J9.2, J10.2, J132.2, J157.26
PIN_27: J1.2, J11.2, J12.2, J37.2, J38.2, J64.2, J79.2, J90.2, J116.2, J131.2, J141.2, J157.27
PIN_28: J22.1, J48.1, J75.1, J101.1, J127.1, J154.1, J155.1, J157.28
PIN_29: J20.1, J46.1, J52.1, J73.1, J99.1, J125.1, J129.1, J157.29
PIN_30: J23.1, J49.1, J76.1, J102.1, J128.1, J144.1, J156.1, J157.30
PWR_1: J157.31, J158.1
PWR_2: J157.32, J158.2

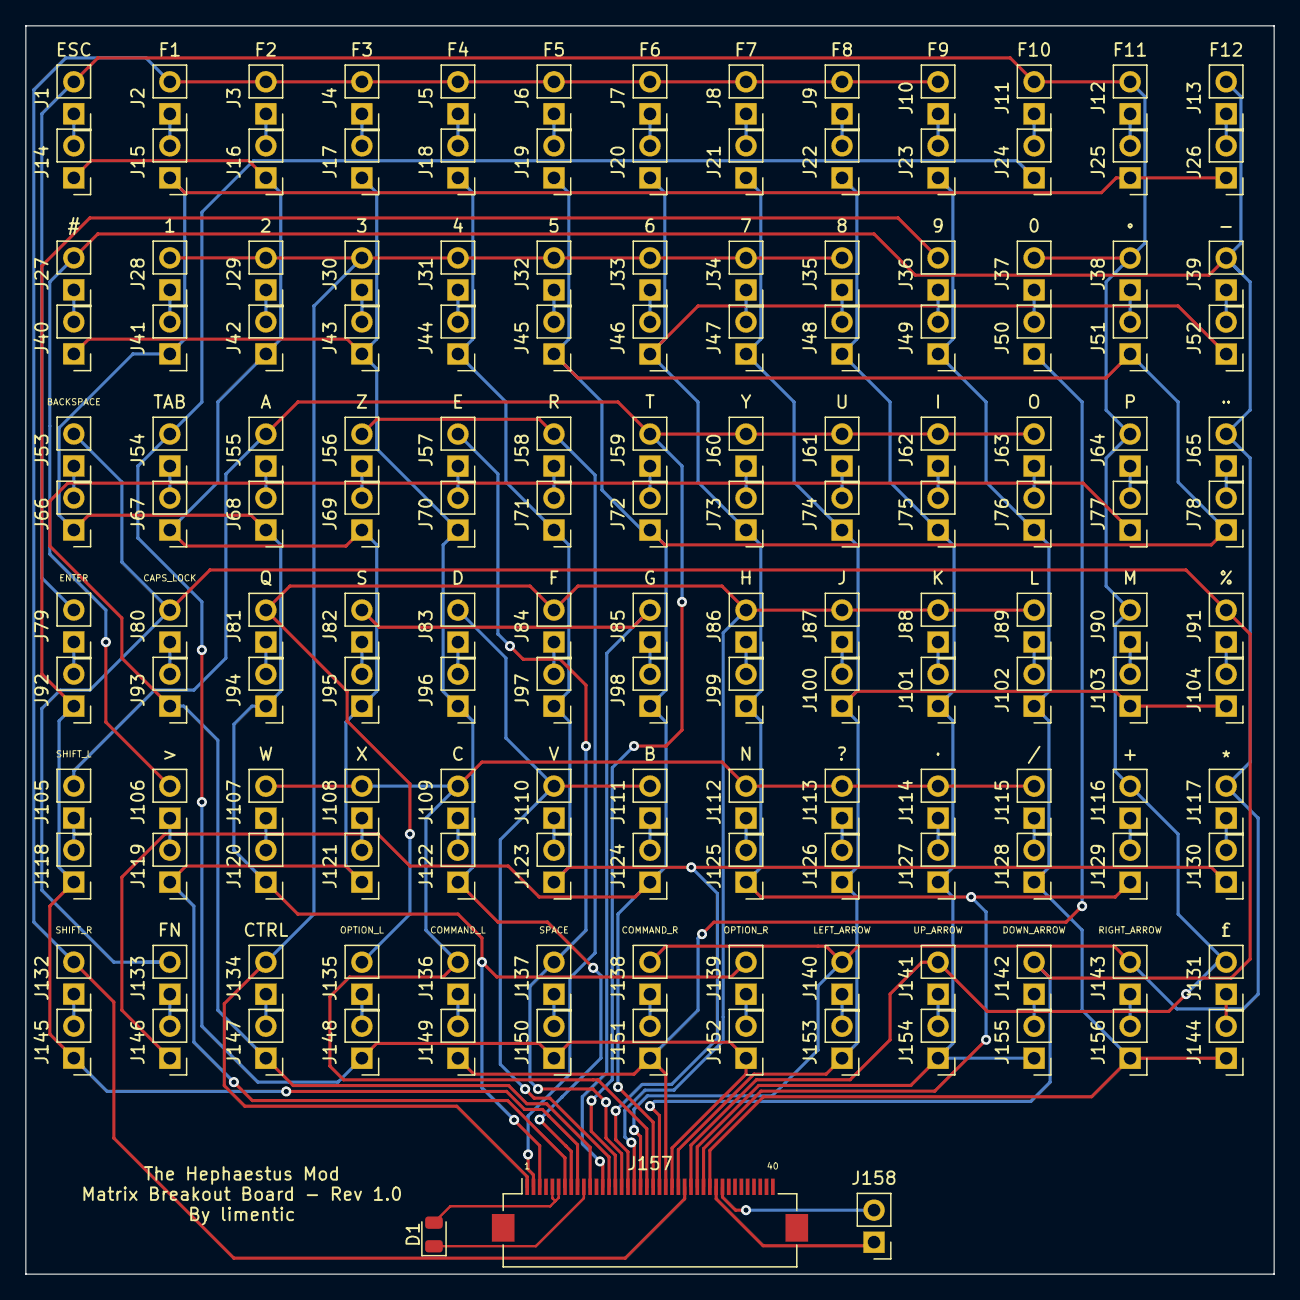
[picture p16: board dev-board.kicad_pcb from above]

Board: 2 copper layers, 99.1 x 99.1 mm, 159 parts (0 on the bottom side), 107 nets.

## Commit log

2024-09-13 Added keycap files.
    [TF22-16S-0.175SHW(800)_4800346000_3D_IGS.igs, keyboard.kicad_pcb, keycap-cover.stl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]
2024-10-04 Removed wrong size .stl and replaced them with .step files.
    [keycap-cover.step, keycap-cover.stl, keycap-stem.step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]
